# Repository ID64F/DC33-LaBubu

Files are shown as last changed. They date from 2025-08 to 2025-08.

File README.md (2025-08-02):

# DC33-LaBubu

## JLCPCB PCB Colors & Components
- ENIG Copper
- White Silk
- Mask
    * Red
    * Blue
    * Purple
    * Green 
    * Yellow
    * White
    * Black
- Components
    * 1206 SMD LEDs HandSoldering
    * 1206 SMD Resistors HandSoldering
    * 1206 SMD Capacitor HandSoldering
    * Attiny85
    * MCP23017
    * CR2032 Battery Holder
    * Switch
    * SAO Connector
<div align="center">
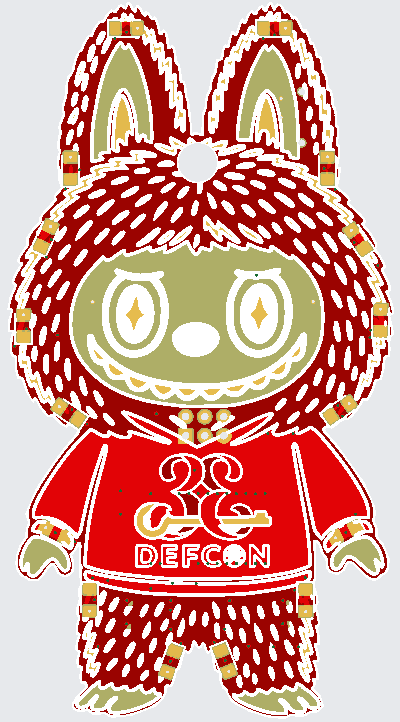
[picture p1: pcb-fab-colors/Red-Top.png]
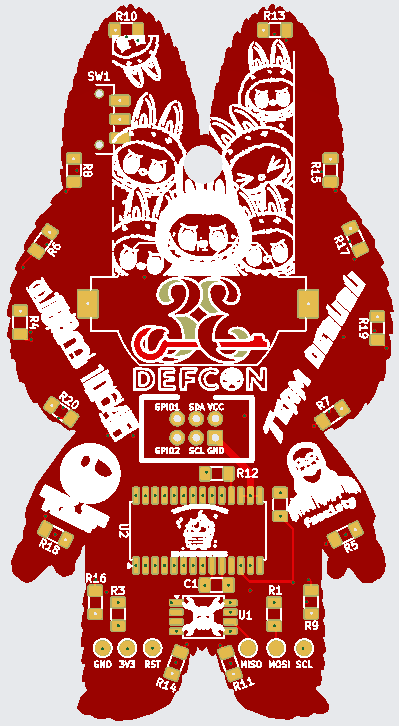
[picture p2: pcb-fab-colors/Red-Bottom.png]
 
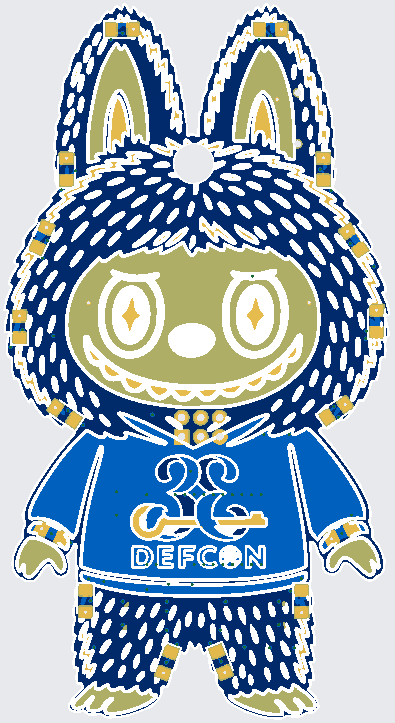
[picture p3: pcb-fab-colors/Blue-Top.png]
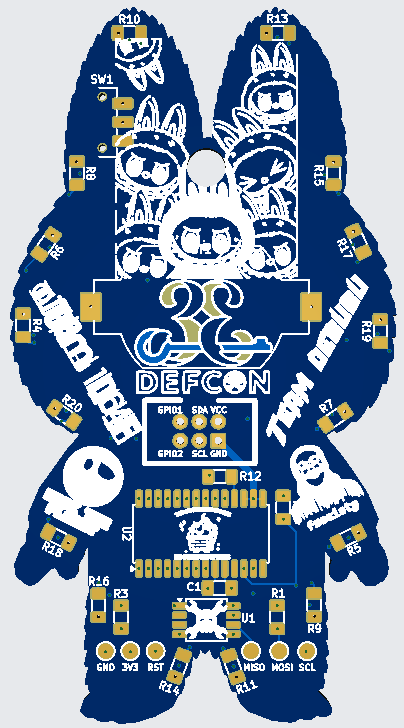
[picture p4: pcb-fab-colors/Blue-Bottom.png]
 
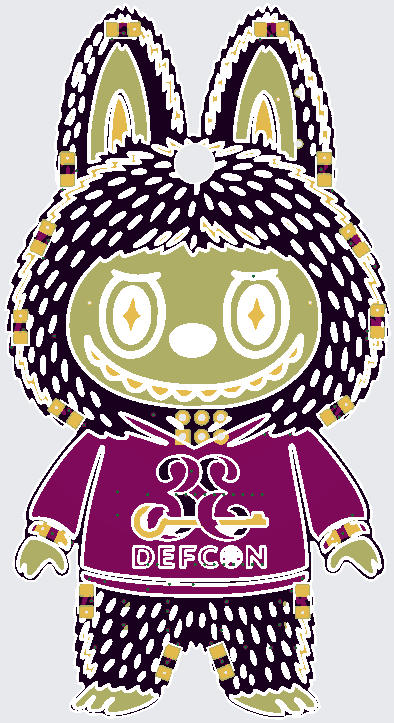
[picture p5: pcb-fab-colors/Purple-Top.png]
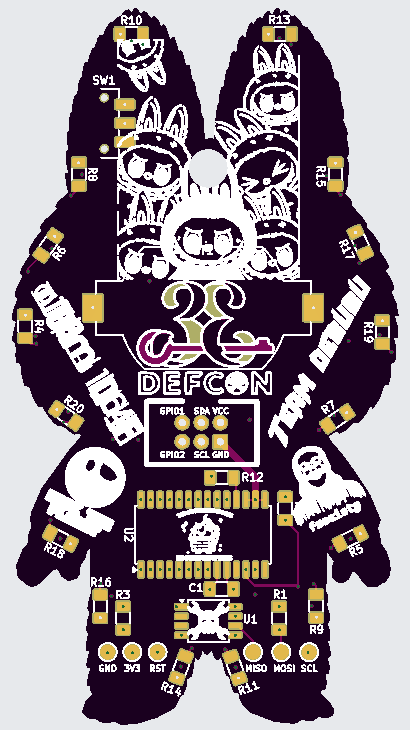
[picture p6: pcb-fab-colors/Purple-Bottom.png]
 
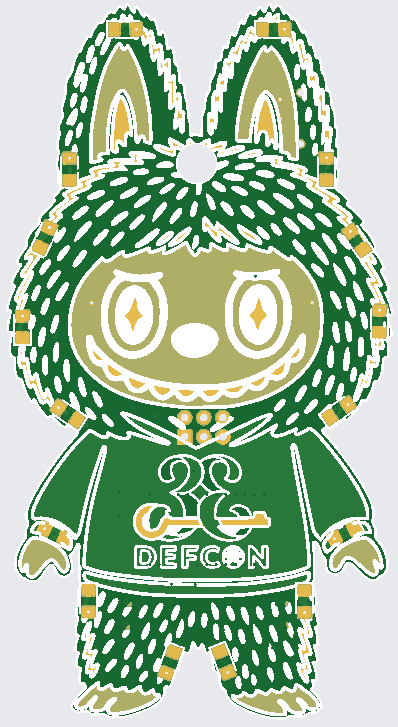
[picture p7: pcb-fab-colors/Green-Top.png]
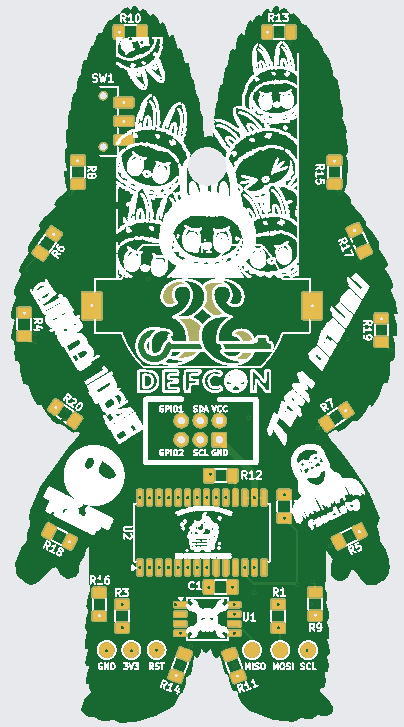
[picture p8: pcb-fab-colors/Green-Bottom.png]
 
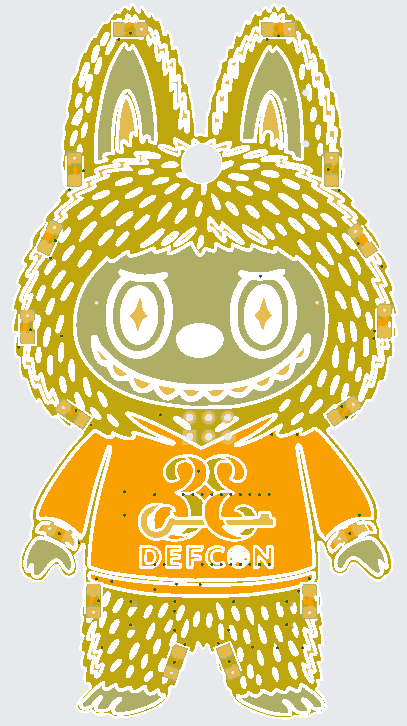
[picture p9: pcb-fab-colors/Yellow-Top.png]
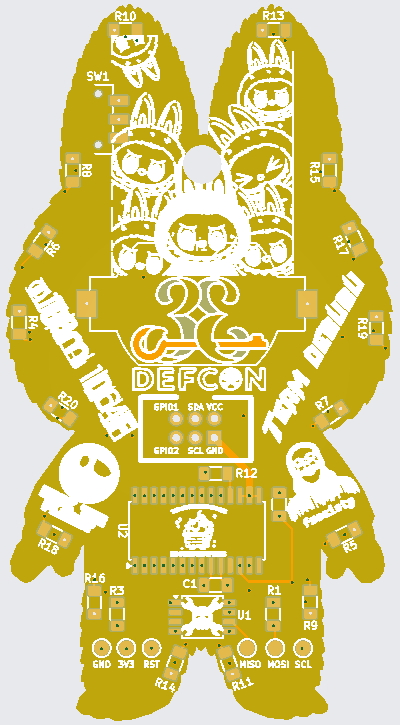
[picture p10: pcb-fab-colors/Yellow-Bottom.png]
 
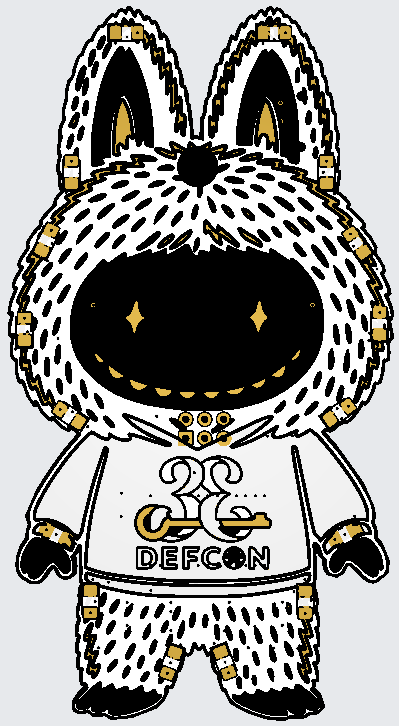
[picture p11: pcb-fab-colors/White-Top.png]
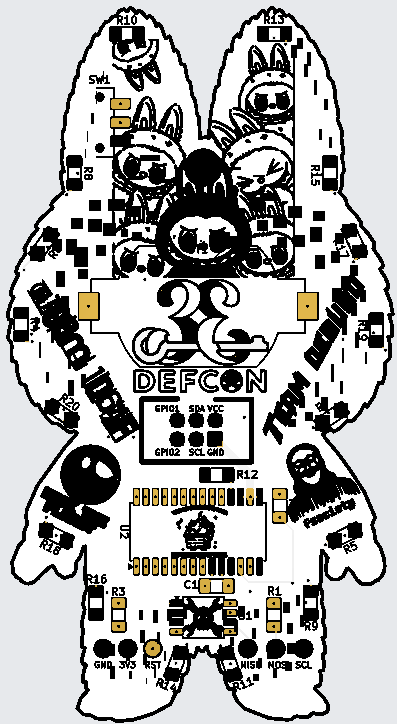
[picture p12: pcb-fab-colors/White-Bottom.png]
 
</div>
<div align="center">
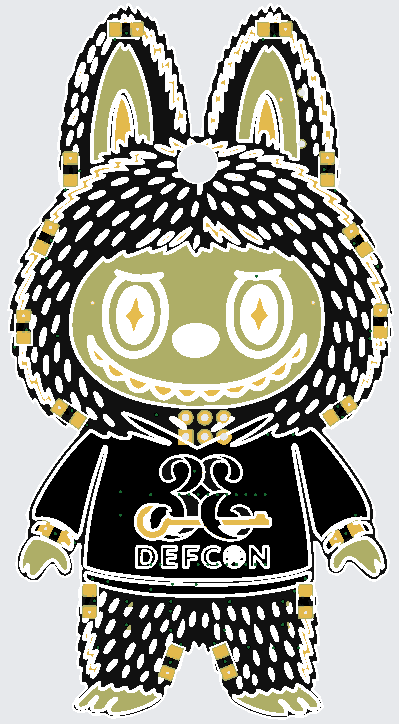
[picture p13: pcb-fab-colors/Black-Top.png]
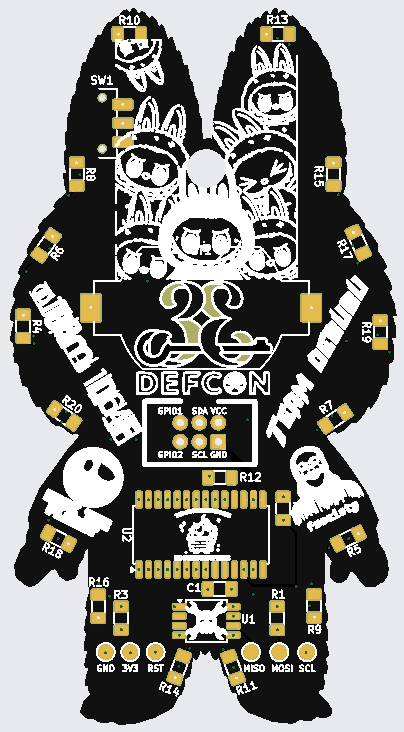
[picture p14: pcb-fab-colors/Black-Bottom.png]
 
</div>

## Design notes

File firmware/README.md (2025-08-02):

This code is optimized for ultra-low power consumption with a CR2032 battery. Here are the key power-saving features:
Power Optimizations:

Uses SLEEP_MODE_PWR_DOWN (lowest power mode ~0.1µA)
Disables unused peripherals (ADC, Timer1)
Uses watchdog timer for timing instead of active delays
I2C runs at 100kHz to reduce power consumption
LEDs flash briefly (500ms) to minimize current draw

Key Features:

Controls 16 LEDs (8 on each MCP23017 port)
Each LED flashes for exactly 500ms
Cycles through all LEDs sequentially
Optional 10-second sleep between full cycles

Power Consumption Estimates:

Sleep mode: ~0.1µA (ATtiny85) + ~1µA (MCP23017)
Active mode: ~1mA (ATtiny85) + ~1mA (MCP23017) + LED current
With typical LEDs (~10mA each), total active current ~22mA per LED

Battery Life:
With a 220mAh CR2032, assuming 500ms on per LED every ~20 seconds, you should get several months of operation.
Programming Notes:

Use Arduino IDE with ATtiny85 board support
You'll need the Wire library (should work with TinyWireM as well)
Program using ISP programmer or Arduino as ISP

The wiring diagram is included in the comments. Make sure to add pullup resistors for I2C and current limiting resistors for LEDs!

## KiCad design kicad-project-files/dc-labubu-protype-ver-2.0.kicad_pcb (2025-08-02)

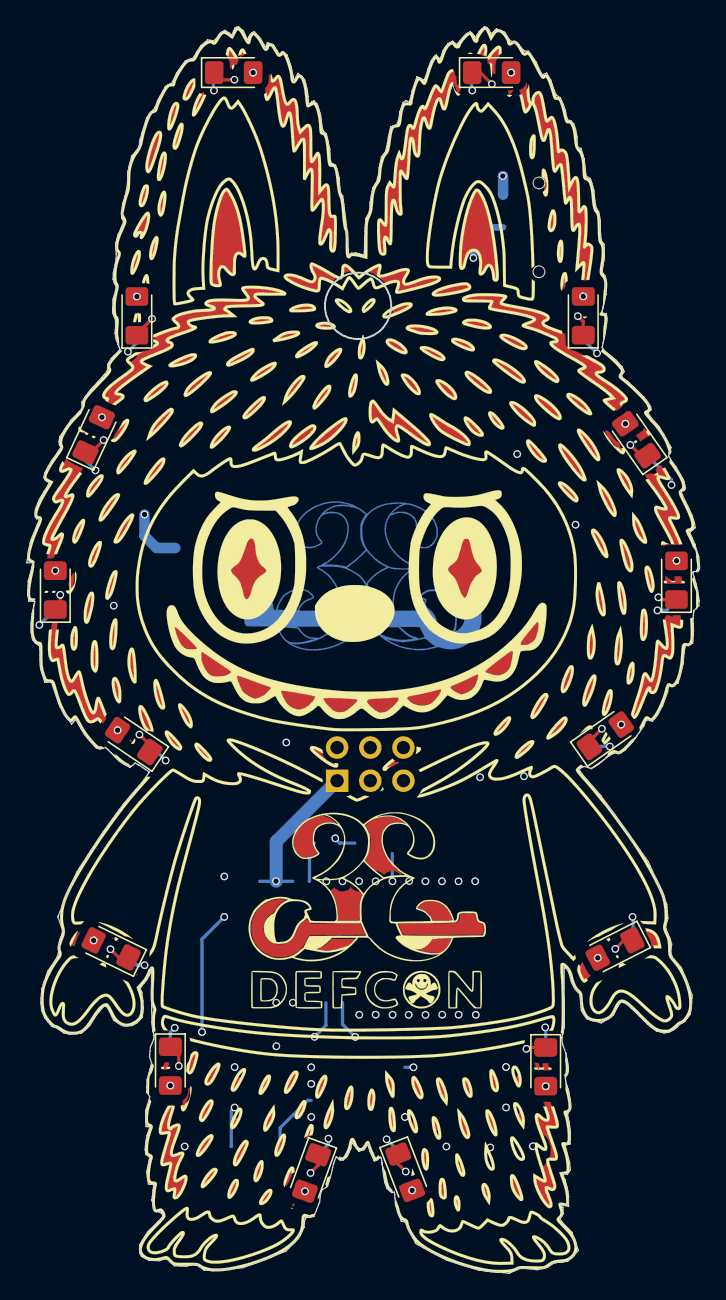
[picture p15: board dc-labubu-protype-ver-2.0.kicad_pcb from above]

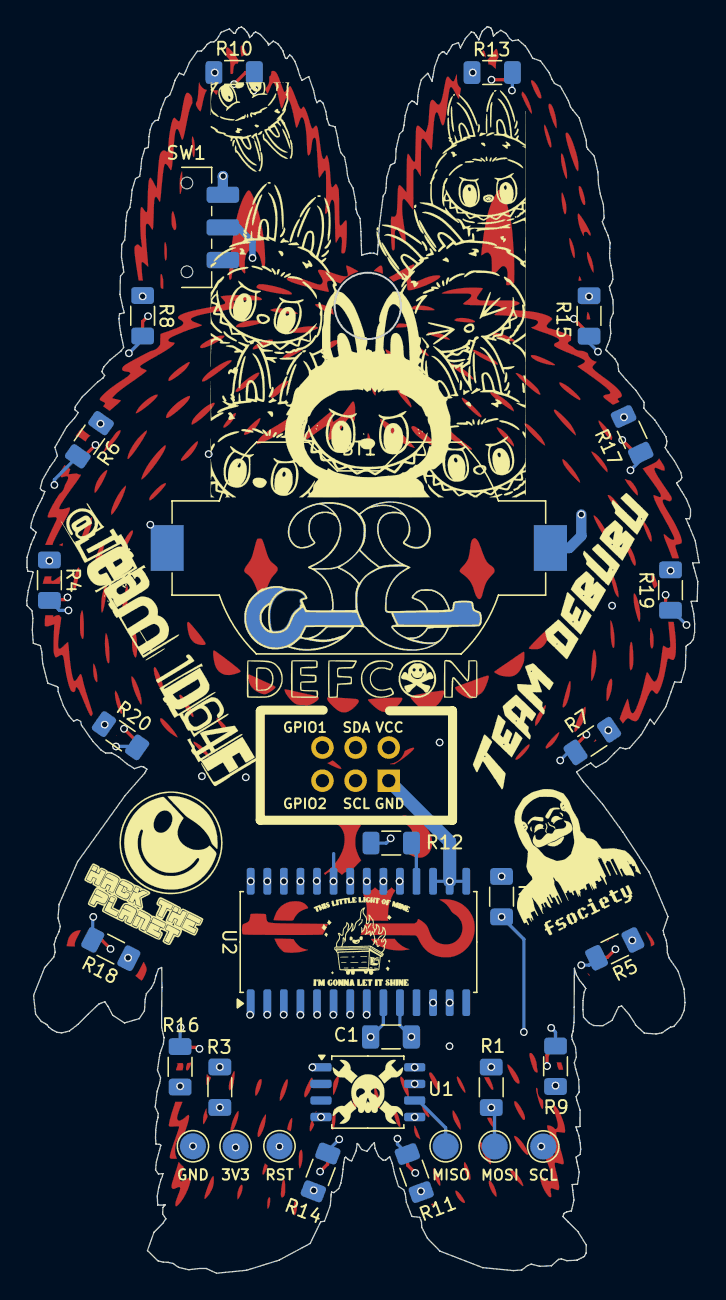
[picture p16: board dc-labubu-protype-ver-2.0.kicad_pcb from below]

Board: 4 copper layers, 51.5 x 95.5 mm, 49 parts (31 on the bottom side), 42 nets.

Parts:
3V3: +3V3; TestPoint_Pad_D2.0mm
BT1: Battery_Cell; BatteryHolder_Keystone_1058_1x2032
C1: 0.1µF; C_1206_3216Metric_Pad1.33x1.80mm_HandSolder
D1, D2, D3, D4, D5, D6, D7, D8, D9, D10, D11, D12, D13, D14, D15, D16: LED; LED_1206_3216Metric_Pad1.42x1.75mm_HandSolder
GND: GND; TestPoint_Pad_D2.0mm
MISO: MISO; TestPoint_Pad_D2.0mm
MOSI: MOSI (SDA); TestPoint_Pad_D2.0mm
R1, R2: 4.7k; R_1206_3216Metric_Pad1.30x1.75mm_HandSolder
R3, R12: 10kΩ; R_1206_3216Metric_Pad1.30x1.75mm_HandSolder
R4, R5, R6, R7, R8, R9, R10, R11, R13, R14, R15, R16, R17, R18, R19, R20: 220Ω; R_1206_3216Metric_Pad1.30x1.75mm_HandSolder
RST: RESET; TestPoint_Pad_D2.0mm
Ref**: Val**; dc-labubu-protype-ver-2.0
SCL: SCK (SCL); TestPoint_Pad_D2.0mm
SW1: SW_SPST; SW_SPDT_CK_JS102011SAQN
U1: ATtiny85-20S; SOIC-8_5.3x5.3mm_P1.27mm
U2: MCP23017_SO; SOIC-28W_7.5x17.9mm_P1.27mm
X1: Badgelife_sao_connector_v169bis; Badgelife-SAOv169-SAO-2x3

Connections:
+3V3: 3V3.1, C1.2, R1.1, R2.1, R3.1, R12.2, SW1.2 (B), U1.8 (VCC), U2.9 (VDD), X1.1 (VCC)
/BAT+: BT1.1 (+), SW1.1 (A)
/GPA0: R19.2, U2.21 (GPA0)
/GPA1: R17.2, U2.22 (GPA1)
/GPA2: R15.2, U2.23 (GPA2)
/GPA3: R13.2, U2.24 (GPA3)
/GPA4: R10.2, U2.25 (GPA4)
/GPA5: R8.2, U2.26 (GPA5)
/GPA6: R6.2, U2.27 (GPA6)
/GPA7: R4.2, U2.28 (GPA7)
/GPB0: R20.2, U2.1 (GPB0)
/GPB1: R18.2, U2.2 (GPB1)
/GPB2: R16.2, U2.3 (GPB2)
/GPB3: R14.2, U2.4 (GPB3)
/GPB4: R11.2, U2.5 (GPB4)
/GPB5: R9.2, U2.6 (GPB5)
/GPB6: R7.2, U2.7 (GPB6)
/GPB7: R5.2, U2.8 (GPB7)
/GPIO1: U2.20 (INTA), X1.5 (GPIO1)
/GPIO2: U2.19 (INTB), X1.6 (GPIO2)
GND: BT1.2 (-), C1.1, D1.1 (K), D2.1 (K), D3.1 (K), D4.1 (K), D5.1 (K), D6.1 (K), D7.1 (K), D8.1 (K), D9.1 (K), D10.1 (K), D11.1 (K), D12.1 (K), D13.1 (K), D14.1 (K), D15.1 (K), D16.1 (K), GND.1, U1.4 (GND), U2.10 (VSS), U2.15 (A0), U2.16 (A1), U2.17 (A2), X1.2 (GND)
MISO: MISO.1, U1.6 (PB1)
MOSI: MOSI.1, R1.2, U1.5 (AREF/PB0), U2.13 (SDA), X1.3 (SDA)
unnamed: D1.2 (A), R4.1
unnamed: D2.2 (A), R5.1
unnamed: D3.2 (A), R6.1
unnamed: D4.2 (A), R7.1
unnamed: D5.2 (A), R8.1
unnamed: D6.2 (A), R9.1
unnamed: D7.2 (A), R10.1
unnamed: D8.2 (A), R11.1
unnamed: D9.2 (A), R13.1
unnamed: D10.2 (A), R14.1
unnamed: D11.2 (A), R15.1
unnamed: D12.2 (A), R16.1
unnamed: D13.2 (A), R17.1
unnamed: D14.2 (A), R18.1
unnamed: D15.2 (A), R19.1
unnamed: D16.2 (A), R20.1
unnamed: R12.1, U2.18 (~RESET)
RESET: R3.2, RST.1, U1.1 (~RESET/PB5)
SCL: R2.2, SCL.1, U1.7 (PB2), U2.12 (SCK), X1.4 (SCL)

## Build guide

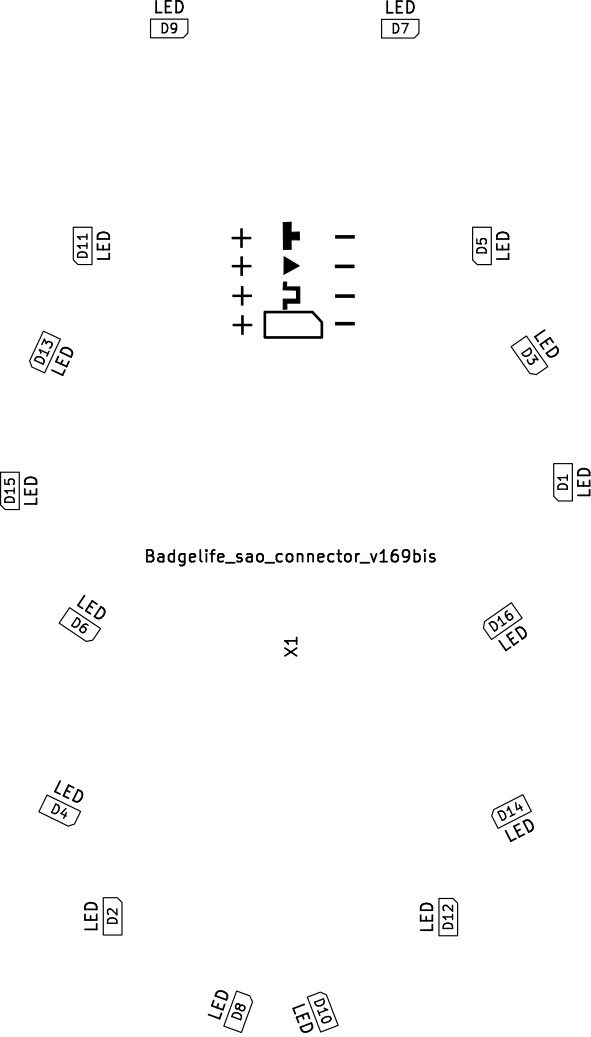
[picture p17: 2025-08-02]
pcb-component-layout/Top_PCB_Soldering_Placement.png

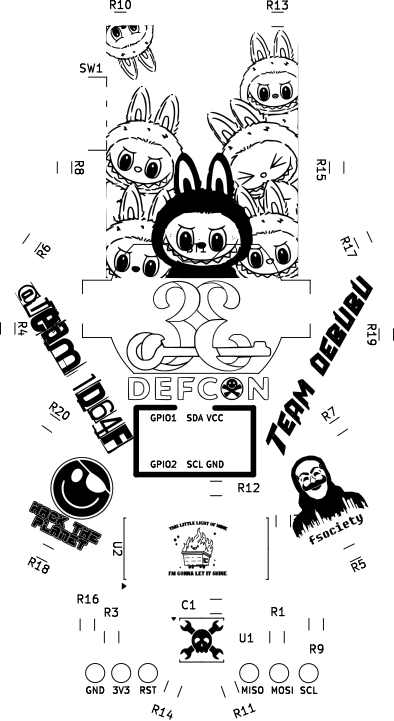
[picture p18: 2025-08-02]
pcb-component-layout/Bottom_PCB_Soldering_Placement.png

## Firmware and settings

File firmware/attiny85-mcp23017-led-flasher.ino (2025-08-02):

#include <Wire.h>
#include <avr/sleep.h>
#include <avr/power.h>
#include <avr/wdt.h>

// MCP23017 I2C address (A0, A1, A2 = LOW)
#define MCP23017_ADDR 0x20

// MCP23017 Register addresses
#define MCP23017_IODIRA   0x00  // I/O Direction Register A
#define MCP23017_IODIRB   0x01  // I/O Direction Register B
#define MCP23017_GPIOA    0x12  // General Purpose I/O Port Register A
#define MCP23017_GPIOB    0x13  // General Purpose I/O Port Register B

// ATtiny85 pins for I2C (using TinyWireM library pins)
// SDA = Pin 0 (PB0)
// SCL = Pin 2 (PB2)

volatile bool wakeUp = false;

void setup() {
  // Disable unused peripherals to save power
  power_adc_disable();
  power_timer1_disable();
  
  // Initialize I2C
  Wire.begin();
  Wire.setClock(100000); // 100kHz for lower power consumption
  
  // Initialize MCP23017
  initMCP23017();
  
  // Setup watchdog timer for 1 second intervals
  setupWatchdog();
  
  // Set sleep mode
  set_sleep_mode(SLEEP_MODE_PWR_DOWN);
}

void loop() {
  // Flash each LED for 500ms
  for (uint8_t port = 0; port < 2; port++) {
    for (uint8_t pin = 0; pin < 8; pin++) {
      // Turn on current LED
      setLED(port, pin, true);
      
      // Wait 500ms using watchdog timer (sleep)
      sleepFor500ms();
      
      // Turn off current LED
      setLED(port, pin, false);
    }
  }
  
  // After cycling through all LEDs, sleep for longer period
  // to conserve battery (optional - remove if continuous cycling desired)
  for (uint8_t i = 0; i < 10; i++) { // Sleep for ~10 seconds
    sleepFor1Second();
  }
}

void initMCP23017() {
  // Set all pins as outputs (0 = output, 1 = input)
  writeRegister(MCP23017_IODIRA, 0x00); // Port A all outputs
  writeRegister(MCP23017_IODIRB, 0x00); // Port B all outputs
  
  // Turn off all LEDs initially
  writeRegister(MCP23017_GPIOA, 0x00);
  writeRegister(MCP23017_GPIOB, 0x00);
}

void writeRegister(uint8_t reg, uint8_t value) {
  Wire.beginTransmission(MCP23017_ADDR);
  Wire.write(reg);
  Wire.write(value);
  Wire.endTransmission();
  
  // Small delay to ensure I2C transaction completes
  delayMicroseconds(100);
}

uint8_t readRegister(uint8_t reg) {
  Wire.beginTransmission(MCP23017_ADDR);
  Wire.write(reg);
  Wire.endTransmission();
  
  Wire.requestFrom(MCP23017_ADDR, 1);
  return Wire.read();
}

void setLED(uint8_t port, uint8_t pin, bool state) {
  uint8_t reg = (port == 0) ? MCP23017_GPIOA : MCP23017_GPIOB;
  uint8_t currentValue = readRegister(reg);
  
  if (state) {
    currentValue |= (1 << pin);   // Set bit
  } else {
    currentValue &= ~(1 << pin);  // Clear bit
  }
  
  writeRegister(reg, currentValue);
}

void setupWatchdog() {
  // Clear the reset flag
  MCUSR &= ~(1 << WDRF);
  
  // Start timed sequence
  WDTCR |= (1 << WDCE) | (1 << WDE);
  
  // Set new watchdog timeout prescaler value to 1 second
  WDTCR = (1 << WDIE) | (1 << WDP2) | (1 << WDP1); // 1 second
}

void sleepFor1Second() {
  wakeUp = false;
  sleep_enable();
  sleep_cpu();
  sleep_disable();
}

void sleepFor500ms() {
  // For 500ms, we'll use two 250ms sleeps or approximate with delay
  // Since watchdog minimum is ~15ms, we'll use a more efficient approach
  
  // Temporarily set watchdog to shorter interval
  WDTCR |= (1 << WDCE) | (1 << WDE);
  WDTCR = (1 << WDIE) | (1 << WDP2); // ~250ms
  
  // Sleep twice for ~500ms
  sleepFor1Second();
  sleepFor1Second();
  
  // Restore 1 second watchdog
  setupWatchdog();
}

// Watchdog interrupt service routine
ISR(WDT_vect) {
  wakeUp = true;
}

/*
 * WIRING:
 * 
 * ATtiny85:
 * Pin 1 (RESET) -> 10kΩ pullup to VCC
 * Pin 4 (GND)   -> Ground
 * Pin 8 (VCC)   -> 3.3V from CR2032
 * Pin 5 (PB0)   -> SDA (MCP23017 pin 13)
 * Pin 7 (PB2)   -> SCL (MCP23017 pin 12)
 * 
 * MCP23017:
 * Pin 9 (VDD)   -> 3.3V
 * Pin 10 (VSS)  -> Ground
 * Pin 12 (SCL)  -> ATtiny85 Pin 7 (PB2) + 4.7kΩ pullup to VCC
 * Pin 13 (SDA)  -> ATtiny85 Pin 5 (PB0) + 4.7kΩ pullup to VCC
 * Pin 15 (A0)   -> Ground (sets I2C address to 0x20)
 * Pin 16 (A1)   -> Ground
 * Pin 17 (A2)   -> Ground
 * Pin 18 (RESET)-> 10kΩ pullup to VCC
 * 
 * Pins 21-28 (GPA0-GPA7) -> LEDs with appropriate current limiting resistors
 * Pins 1-8 (GPB0-GPB7)   -> LEDs with appropriate current limiting resistors
 * 
 * For 3.3V operation with typical LEDs, use ~150-220Ω current limiting resistors
 * 
 * POWER OPTIMIZATION NOTES:
 * - Uses power-down sleep mode (lowest power consumption)
 * - Disables unused peripherals (ADC, Timer1)
 * - Uses watchdog timer for timing instead of active delays
 * - I2C at 100kHz for lower power consumption
 * - LEDs are only on for 500ms each, minimizing current draw
 * - Optional longer sleep periods between LED cycles
 */

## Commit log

2025-08-02 added gerber directory, SVGs and footprints
    [dc-labubu-protype-ver-2.0-B_Cu.gbr, dc-labubu-protype-ver-2.0-B_Mask.gbr, dc-labubu-protype-ver-2.0-B_Silkscreen.gbr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]
2025-08-02 Added kicad-project-files directory and going to add firmware and instructions directory
    [dc-labubu-protype-ver-2.0.kicad_pcb, dc-labubu-protype-ver-2.0.kicad_sch]
2025-08-02 added arduino firmware code to flash SAOs once assembled
2025-08-02 unhide the layers for the pcb from the svg image
2025-08-02 Added pcb colors that were orderd through JLCPCB
2025-08-02 added images and details for pcbs that were ordered
